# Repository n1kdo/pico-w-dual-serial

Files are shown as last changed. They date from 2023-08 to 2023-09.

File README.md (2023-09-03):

# Pico-W Dual Serial 

This is a simple board that supports two RS-232 serial ports (TXD & RXD _only_) with a
Raspberry PI Pico-W.  This is useful to internet-enable devices that support a serial 
interface.

This board is sized for a [Hammond Manufacturing 1591XXSFLBK](https://www.hammfg.com/part/1591XXSFLBK) enclosure.

## Pictures

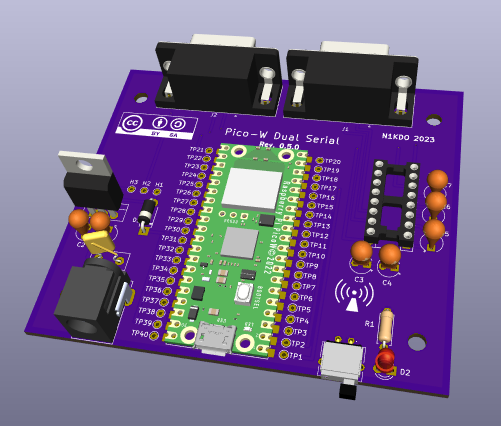
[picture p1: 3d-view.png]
3d view


3-D image from Kicad 

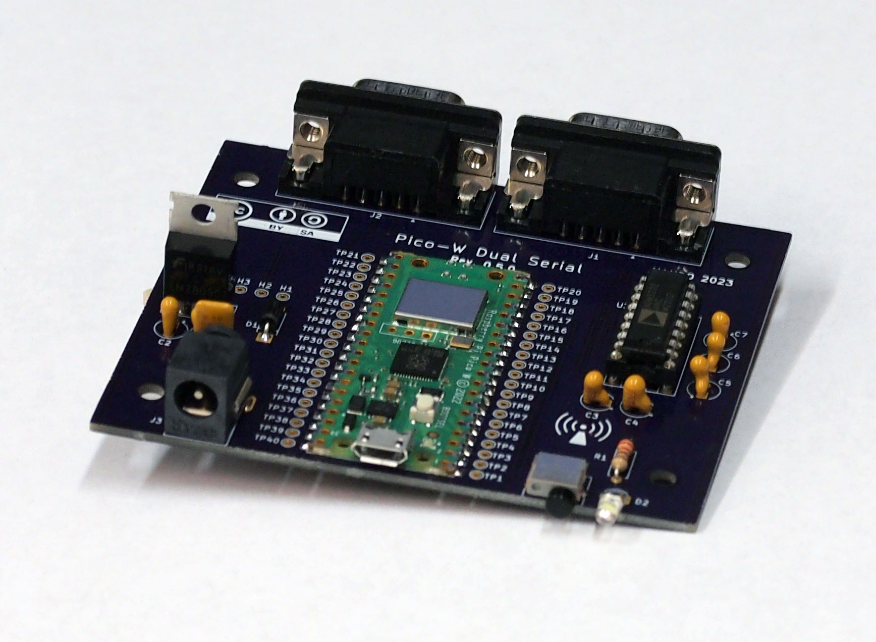
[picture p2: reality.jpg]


Real board!

## Schematic and Bill of Materials

[Schematic PDF](schematic.pdf)

[Bill of Materials](Bill-of-Materials.md)

## License



This work is licensed under a
[Creative Commons Attribution-ShareAlike 4.0 International License](http://creativecommons.org/licenses/by-sa/4.0/).

To view a copy of this license, visit http://creativecommons.org/licenses/by-sa/4.0/ or send a letter to Creative Commons, PO Box 1866, Mountain View, CA 94042, USA.

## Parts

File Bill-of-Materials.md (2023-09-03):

# Bill of Materials for Pico-W Dual Serial

| Item | Qty | Reference(s) | Description | MANUFACTURER | Part Number |
|---|-----|---|---|---|---|
| 1 | 7 | C1, C2, C3, C4, C5, C6, C7 | .1 uF 35V tantalum capacitor | Kemet | T350A104M035AT | 
| 2 | 1 | D1 | 1N5819 1A Schottky Diode | STMicroelectronics | 1N5819 |
| 3 | 1 | D2 | White LED | LiteOn | LTW-420D7 |
| 4 | 1 | F1 | Resettable fuse 0.9A | Littelfuse | RUEF090 |
| 5 | 2 | J1, J2 | DB9_Male | Amphenol | L717SDE09PA4CH4RC309 |
| 6 | 1 | J3 | DC Coaxial Power Connector 2 mm pin | Switchcraft | RAPC722X |
| 7 | 1 | R1 | 330 Ohm 1/4 watt through hole resistor | YAGEO | CFR-25JT-52-330R |
| 8 | 1 | SW1 | Pushbutton switch | NKK Switches | GB215AHB |
| 9 | 1 | n/a | Switch cap | NKK Switches | AT4063 |
| 10 | 1 | U1 | Raspberry Pi Pico W | Raspberry Pi Ltd | SCO918 |
| 11 | 1 | U2 | MAX3232 *or* ADM3202ANZ | Analog Devices / Maxim | MAX3232ECPE+ *or* ADM3202ANZ |
| 12 | 1 | U3 | 5 volt linear voltage regulator | STMicroelectronics | L7805CV |
| 13 | 1 | n/a | 16-pin DIP socket | Mill-Max | 110-47-316-41-001000 |
| 13 | 1 | n/a | Flanged plastic enclosure | Hammond Manufacturing  | 1591XXSFLBK | 
| 14 | 1 | n/a | Printed Circuit Board | your choice | n/a |

## Notes

The MAX3232 is crazy expensive, I have found that the ADM3203ANZ works just as well in this circuit.  If you feel that
you need the additional ESD protection, by all means, use the more expensive part.  

The specified IC socket is a 'machined-pin' style socket.  Cheaper alternatives exist.

There is no need to use a white LED, you can use whatever color you like.  I just think the white ones look cool.

Almost all of these parts were ordered from Mouser.  I was surprised to see they are stocking the Raspberry PI Pico W.
They were pretty scarce at first.  Also Digikey.

The circuit board is up to you.  I have bought these from both [Oshpark](https://www.oshpark.com) and 
[DKRed](https://www.digikey.com/en/resources/dkred) -- neither is inexpensive in small prototype runs.  I think the 
last order for Oshpark was about $60 for three boards, and DKRed was a little cheaper.  Both seem to be of good 
quality.  DKRed can accept Kicad files directly, even though it asked for Gerbers.  

I built the prototype on perf-board, there is no requirement for the printed circuit board, it is just
easier and less error-prone than point-to-point wiring.

The board is designed to fit into the specified Hammond enclosure.  You will need to cut out holes for the DE9 
connectors, the power socket, and the LED and push button.

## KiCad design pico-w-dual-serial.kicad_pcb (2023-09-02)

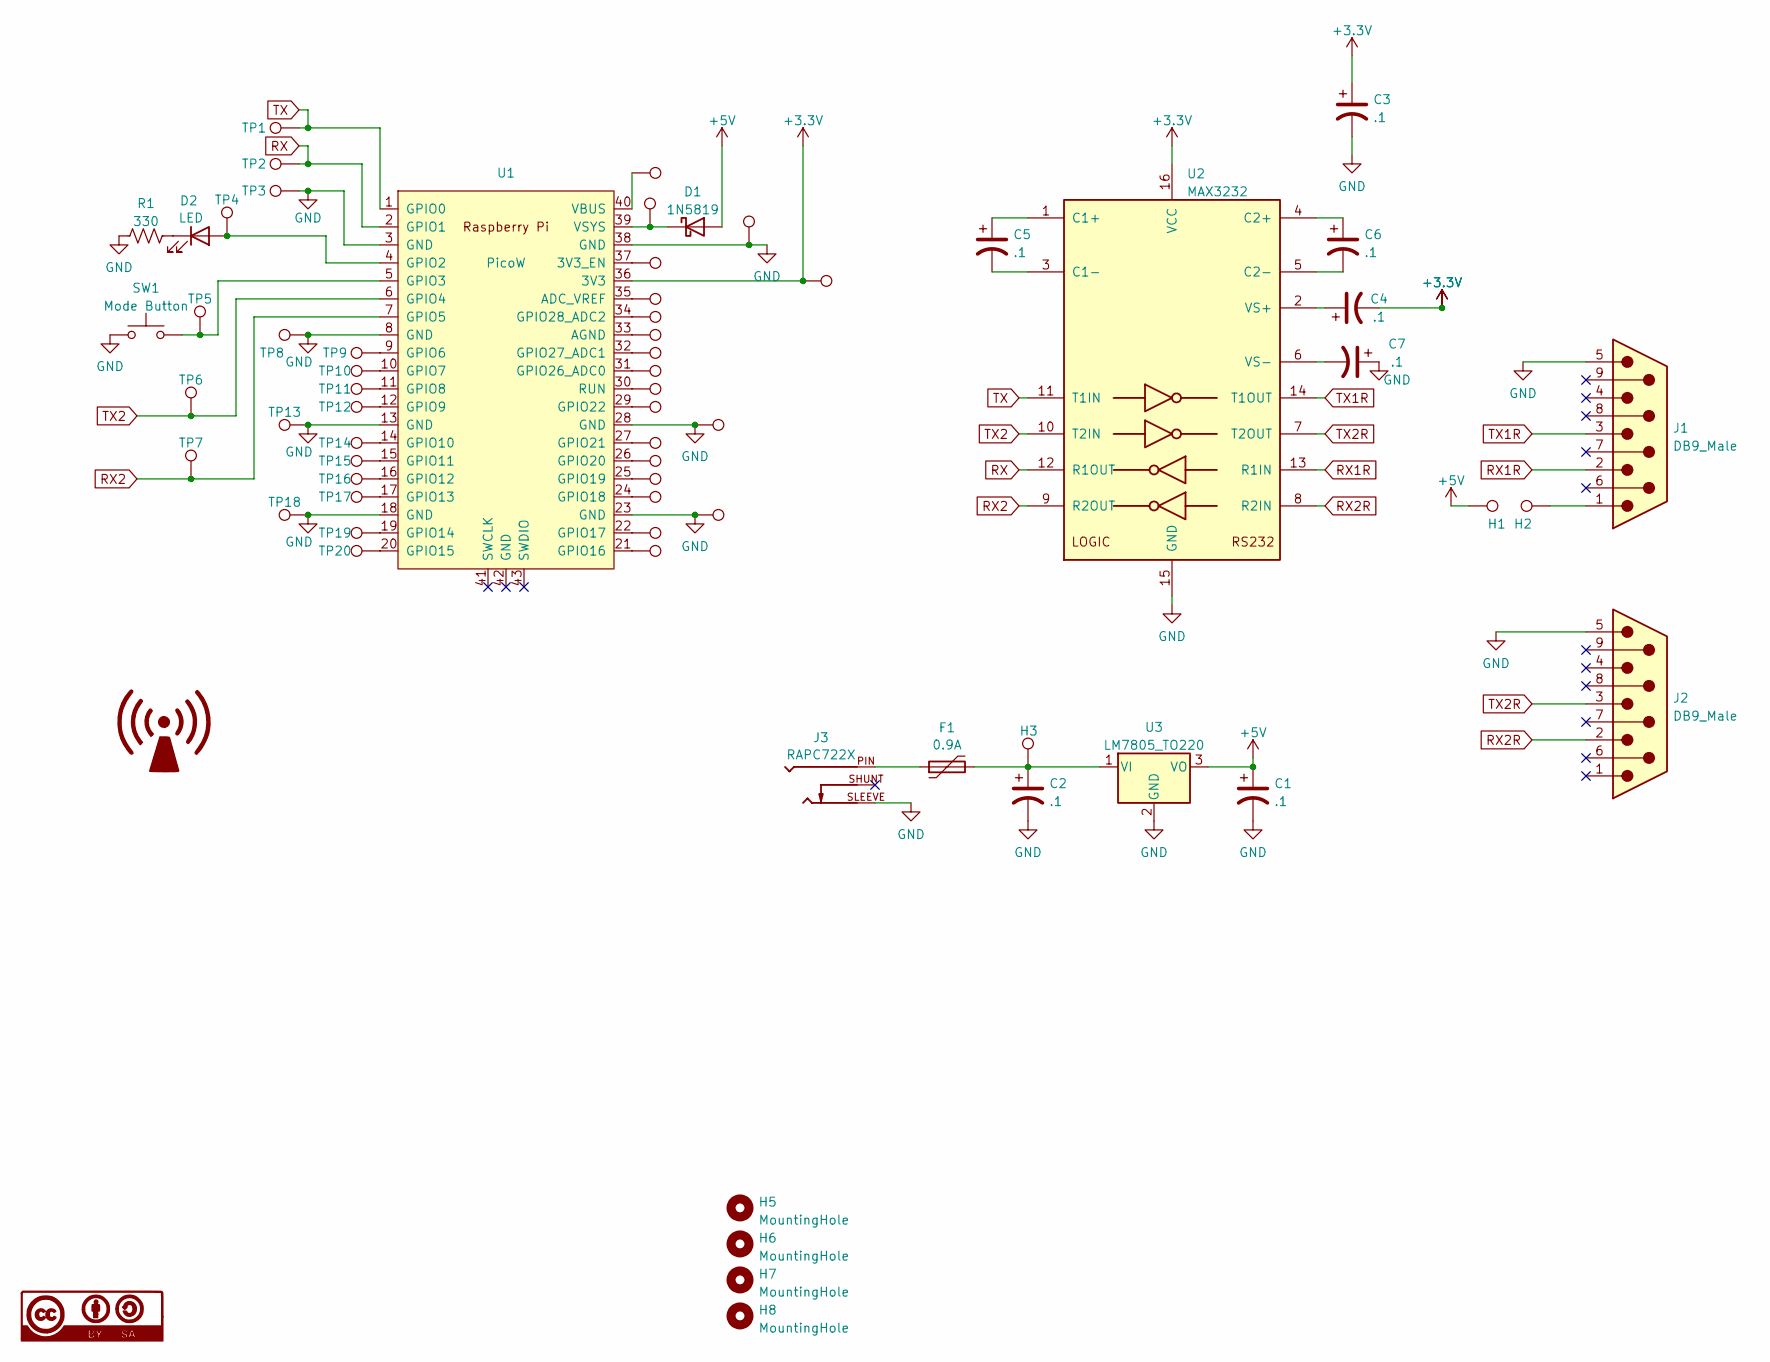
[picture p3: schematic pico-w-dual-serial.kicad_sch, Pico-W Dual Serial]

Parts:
C1, C2, C3, C4, C5, C6, C7: .1; CP_Radial_Tantal_D4.5mm_P2.50mm; part T350A104M035AT
D1: 1N5819; D_DO-41_SOD81_P7.62mm_Horizontal
D2: LED; LED_D3.0mm
F1: 0.9A; RUEF090
H1, H3: 2; TestPoint_THTPad_D1.5mm_Drill0.7mm
H2: 1; TestPoint_THTPad_D1.5mm_Drill0.7mm
H5, H6, H7, H8: MountingHole; MountingHole_3.5mm
J1, J2: DB9_Male; DSUB-9_Male_Horizontal_P2.77x2.84mm_EdgePinOffset4.94mm_Hou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; part L717SDE09PA4CH4RC309
J3: RAPC722X; SWITCHCRAFT_RAPC722X; PARTREV A
R1: 330; R_Axial_DIN0207_L6.3mm_D2.5mm_P7.62mm_Horizontal
SW1: Mode Button; GB215AHB; part GB215AH
TP1, TP2, TP3, TP4, TP5, TP6, TP7, TP8, TP9, TP10, TP11, TP12, TP13, TP14, TP15, TP16, TP17, TP18, TP19, TP20, TP21, TP22, TP23, TP24, TP25, TP26, TP27, TP28, TP29, TP30, TP31, TP32, TP33, TP34, TP35, TP36, TP37, TP38, TP39, TP40: TestPoint; TestPoint_THTPad_D1.5mm_Drill0.7mm
U1: PicoW; RPi_PicoW_SMD_TH
U2: MAX3232; DIP-16_W7.62mm_Socket
U3: LM7805_TO220; TO-220-3_Vertical

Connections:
+3.3V: C3.1, C4.2, TP36.1, U1.36 (3V3), U2.16 (VCC)
+5V: C1.1, D1.2 (A), H1.1, U3.3 (VO)
GND: C1.2, C2.2, C3.2, C7.1, J1.5, J2.5, J3.SLEEVE, R1.1, SW1.1, TP3.1, TP8.1, TP13.1, TP18.1, TP23.1, TP28.1, TP38.1, U1.3 (GND), U1.8 (GND), U1.13 (GND), U1.18 (GND), U1.23 (GND), U1.28 (GND), U1.38 (GND), U2.15 (GND), U3.2 (GND)
unnamed: D1.1 (K), TP39.1, U1.39 (VSYS)
unnamed: D2.2 (A), TP4.1, U1.4 (GPIO2)
unnamed: D2.1 (K), R1.2
unnamed: F1.1, J3.PIN
unnamed: H2.1, J1.1
unnamed: TP37.1, U1.37 (3V3_EN)
unnamed: TP35.1, U1.35 (ADC_VREF)
unnamed: TP33.1, U1.33 (AGND)
unnamed: SW1.2, TP5.1, U1.5 (GPIO3)
unnamed: TP9.1, U1.9 (GPIO6)
unnamed: TP10.1, U1.10 (GPIO7)
unnamed: TP11.1, U1.11 (GPIO8)
unnamed: TP12.1, U1.12 (GPIO9)
unnamed: TP14.1, U1.14 (GPIO10)
unnamed: TP15.1, U1.15 (GPIO11)
unnamed: TP16.1, U1.16 (GPIO12)
unnamed: TP17.1, U1.17 (GPIO13)
unnamed: TP19.1, U1.19 (GPIO14)
unnamed: TP20.1, U1.20 (GPIO15)
unnamed: TP21.1, U1.21 (GPIO16)
unnamed: TP22.1, U1.22 (GPIO17)
unnamed: TP24.1, U1.24 (GPIO18)
unnamed: TP25.1, U1.25 (GPIO19)
unnamed: TP26.1, U1.26 (GPIO20)
unnamed: TP27.1, U1.27 (GPIO21)
unnamed: TP29.1, U1.29 (GPIO22)
unnamed: TP31.1, U1.31 (GPIO26_ADC0)
unnamed: TP32.1, U1.32 (GPIO27_ADC1)
unnamed: TP34.1, U1.34 (GPIO28_ADC2)
unnamed: TP30.1, U1.30 (RUN)
unnamed: TP40.1, U1.40 (VBUS)
unnamed: C5.1, U2.1 (C1+)
unnamed: C5.2, U2.3 (C1-)
unnamed: C6.1, U2.4 (C2+)
unnamed: C6.2, U2.5 (C2-)
unnamed: C4.1, U2.2 (VS+)
unnamed: C7.2, U2.6 (VS-)
unnamed: C2.1, F1.2, H3.1, U3.1 (VI)
RX: TP2.1, U1.2 (GPIO1), U2.12 (R1OUT)
RX1R: J1.2, U2.13 (R1IN)
RX2: TP7.1, U1.7 (GPIO5), U2.9 (R2OUT)
RX2R: J2.2, U2.8 (R2IN)
TX: TP1.1, U1.1 (GPIO0), U2.11 (T1IN)
TX1R: J1.3, U2.14 (T1OUT)
TX2: TP6.1, U1.6 (GPIO4), U2.10 (T2IN)
TX2R: J2.3, U2.7 (T2OUT)

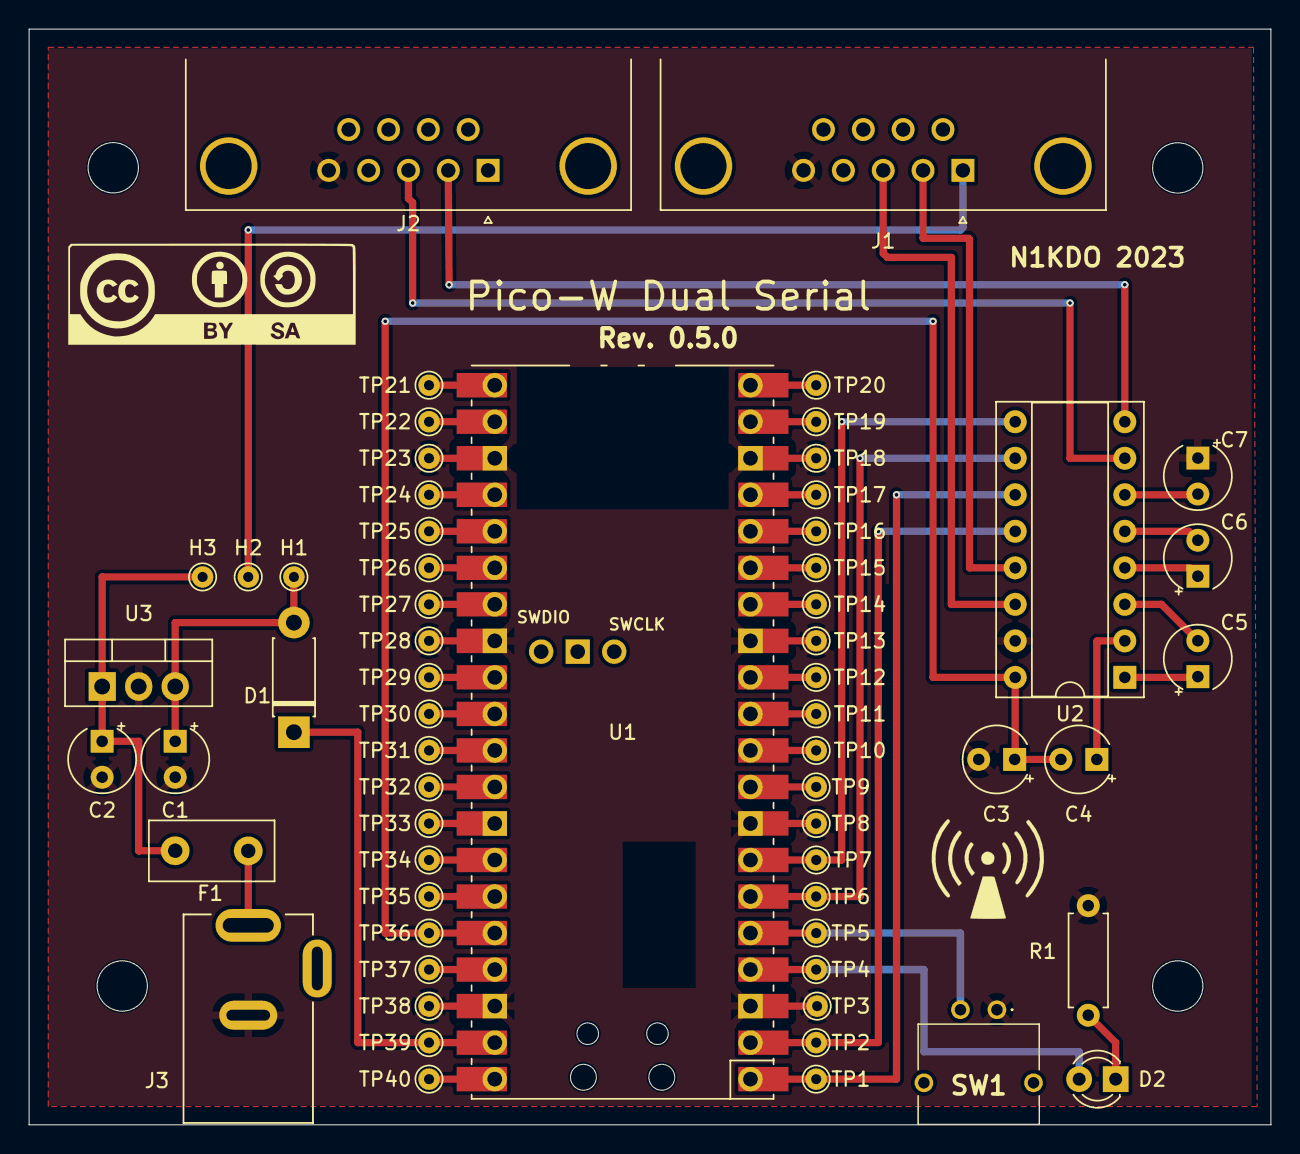
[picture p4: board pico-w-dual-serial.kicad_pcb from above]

Board: 2 copper layers, 86.4 x 76.2 mm, 66 parts (0 on the bottom side), 49 nets.

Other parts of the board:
G1: LOGO; non-ionizing-bigger

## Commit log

2023-08-06 initial commit.
    [pico-w-dual-serial.kicad_pcb, pico-w-dual-serial.kicad_sch]
2023-08-06 add enclosure information
2023-08-14 fix reversed TX2/RX2
    [pico-w-dual-serial.kicad_pcb, pico-w-dual-serial.kicad_sch]
2023-08-29 new pic, better BOM
    [pico-w-dual-serial.kicad_pcb, pico-w-dual-serial.kicad_sch]
2023-09-02 validate design rules
    [pico-w-dual-serial.kicad_pcb]
2023-09-03 add bill of materials
2023-09-03 fix schematic, was missing text & etc.
2023-09-03 link to BOM on README.md
2024-02-19 Create .gitattributes for github-linguist
    try to fix language detection.
    hide .kicad_sch files (there are one) on order taht
    .kicad_pcb files (there is also one) may be sufficient to trigger
    github-linguist to detect the repository is a kicad pcb

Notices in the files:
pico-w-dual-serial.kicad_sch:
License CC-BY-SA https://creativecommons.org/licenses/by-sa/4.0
